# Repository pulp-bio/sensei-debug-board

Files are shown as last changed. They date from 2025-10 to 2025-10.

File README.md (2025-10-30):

# SENSEI Debug Board

This repository contains the hardware design files for the **SENSEI Debug Board**, a dedicated debugging and programming interface designed to facilitate rapid development and prototyping on the SENSEI platform.

## Overview

The **SENSEI Debug Board** simplifies the development process, facilitating flashing, debugging, and testing hardware designed around the SENSEI Base Board and its extension shields. Both the base board and any additional shield boards can be directly connected.

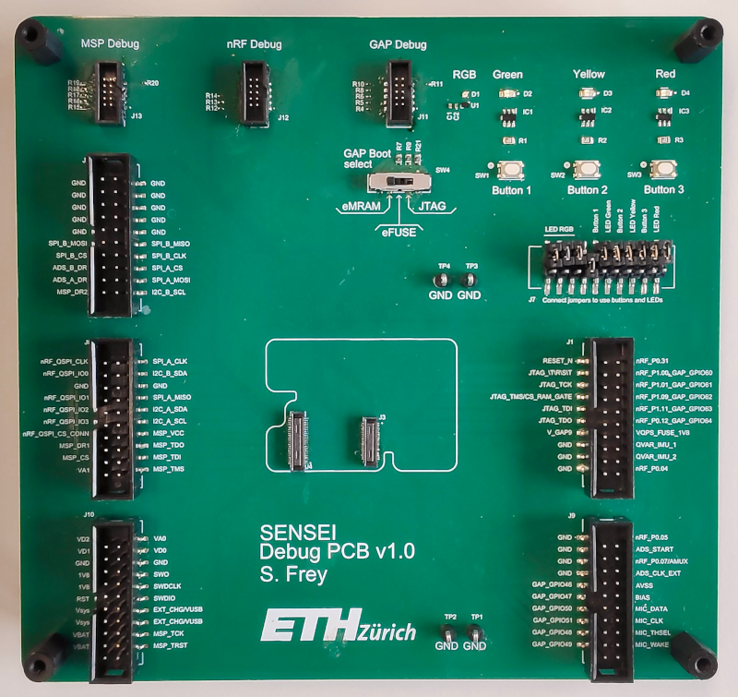
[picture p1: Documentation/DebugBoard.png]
Altium Screenshot


### Key Features
- **Integrated Debug Interfaces**
  - Dedicated debug and flash connectors for GAP9, nRF5340, and MSP SoCs.
- **Easy Signal and Power Access**
  - Pin headers provide direct access to all signals and power rails on the board-to-board connectors.
- **User-Friendly Interface**
  - Onboard LEDs and buttons for system status indication and interaction during development and debugging.

## Important Notes
- For SENSEI Base Board v1.0, ensure that the GAP9 is connected to the SPI bus (controlled by nRF) to use the JTAG programming header on the Debug Board. Alternatively, the JTAG header on the break-off part of the Base Board can be used.

## Changelog
A changelog is available in the [Changelog.md](Changelog.md) file, which tracks all major updates and revisions to the board's design and documentation.

## Contributors
- **Sebastian Frey** ([sefrey@iis.ee.ethz.ch](mailto:sefrey@iis.ee.ethz.ch))
- **Philip Wiese** ([wiesep@iis.ee.ethz.ch](mailto:wiesep@iis.ee.ethz.ch))

## License
This repository makes use of the following licenses:
- for all *hardware*: Solderpad Hardware License Version 0.51
- for all *images*: Creative Commons Attribution 4.0 International
License][cc-by]

For further information have a look at the license files: `LICENSE.hw`, `LICENSE.images`

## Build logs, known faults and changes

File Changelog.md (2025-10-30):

# Changelog

## Version 1.1 (unreleased)
- Added reset buttons
- Changed header for jumpers
- Added note about SENSEI Base Board v1.0 to enable programming

## Version 1.0 (03.07.2025)
- Inital version

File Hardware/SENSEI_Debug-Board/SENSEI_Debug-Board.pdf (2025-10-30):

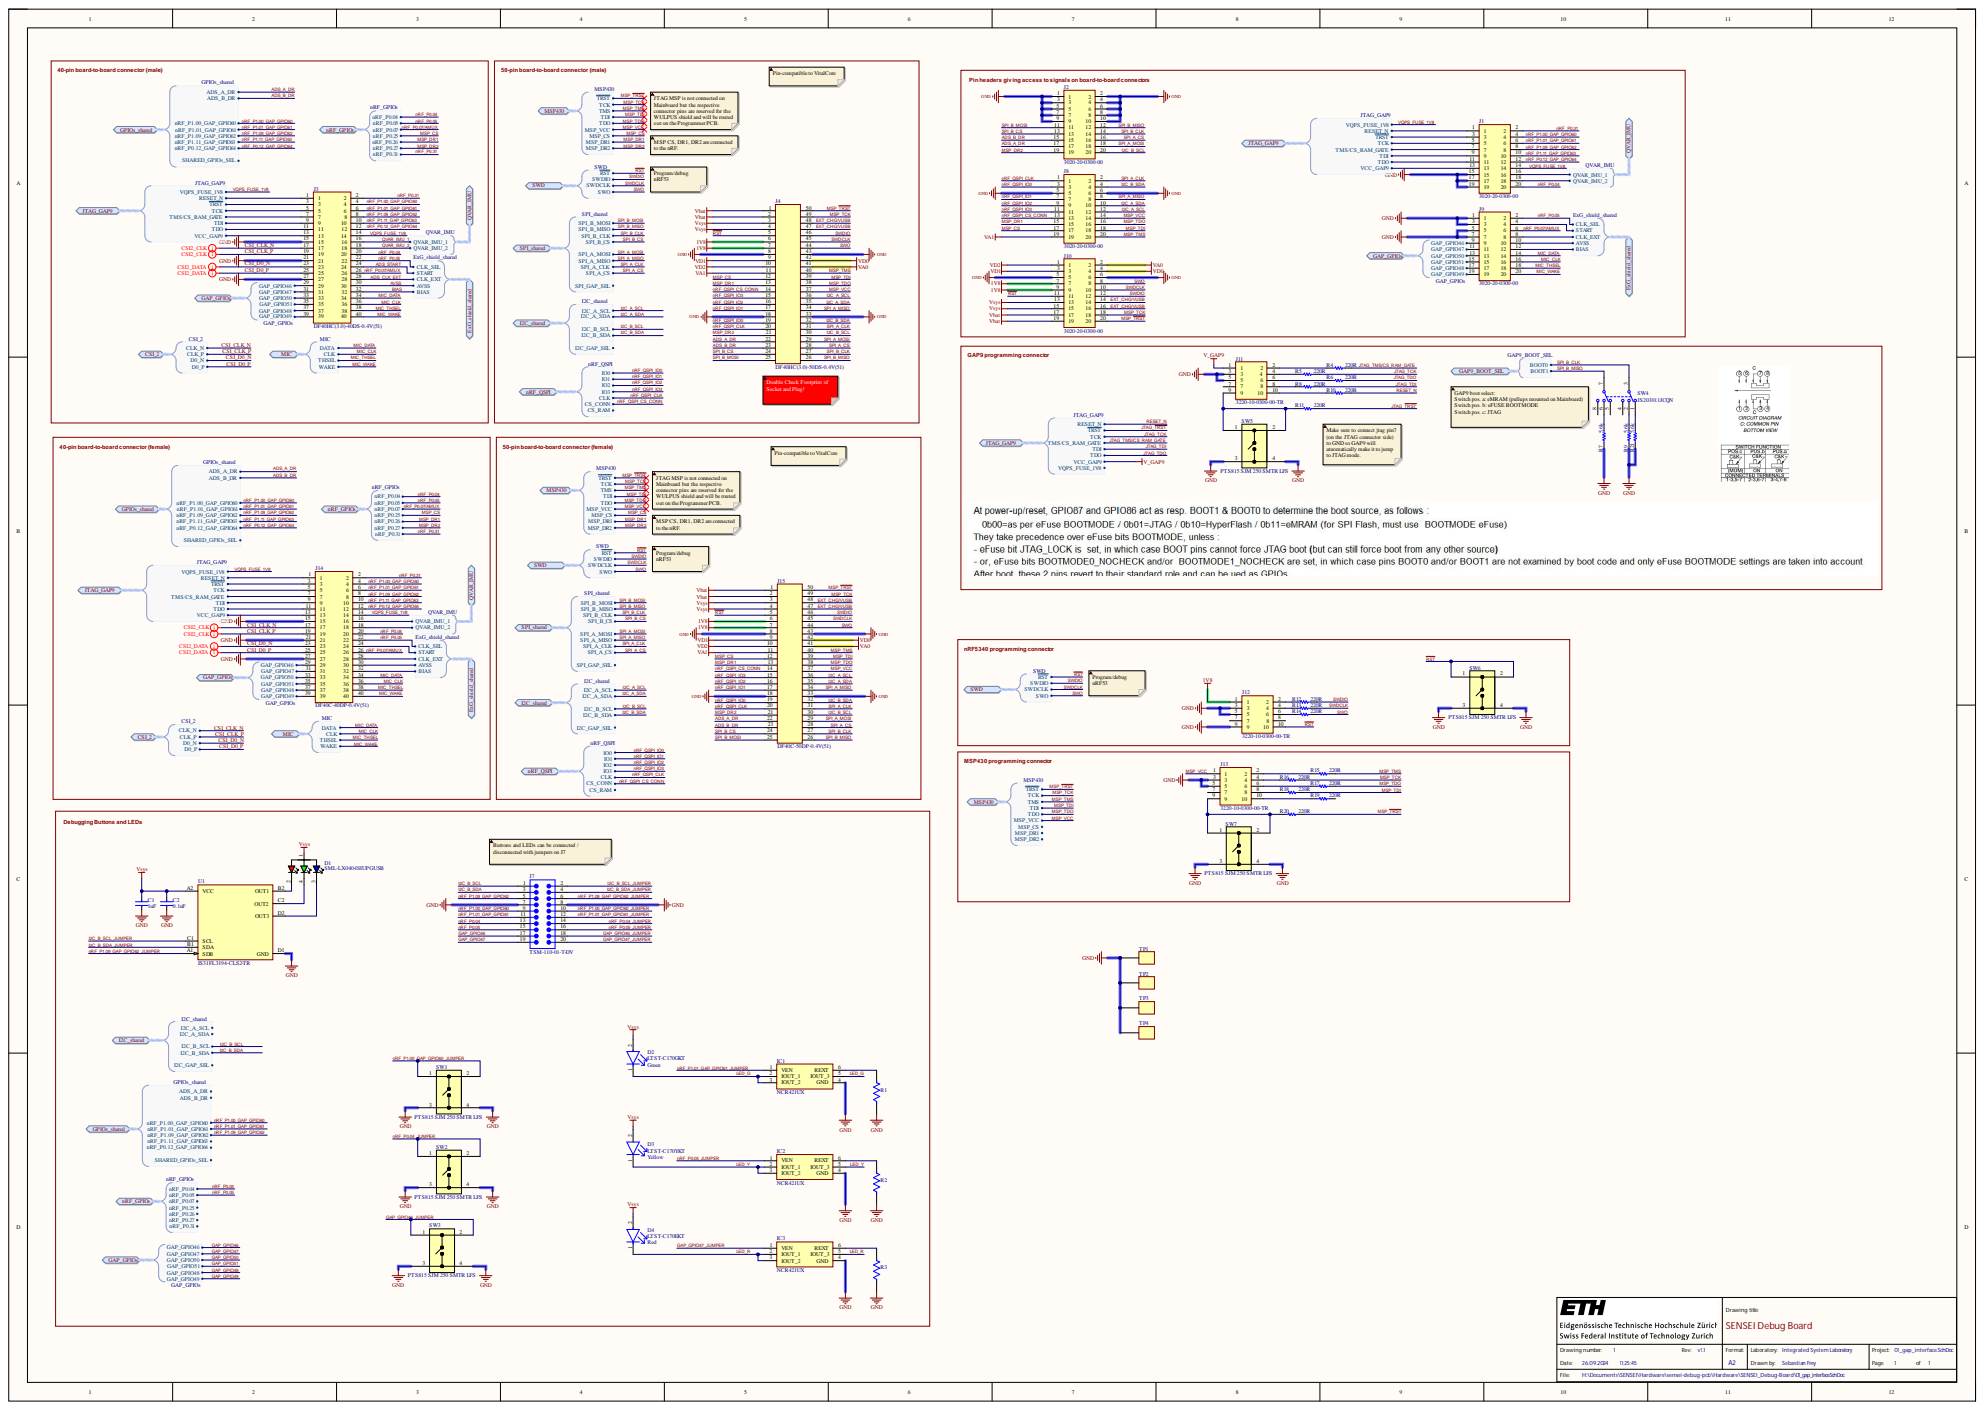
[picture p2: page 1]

40-pin board-to-board connector (male)

50-pin board-to-board connector (male)

Pin-compatible to VitalCore

Pin headers giv ing access to signals on board-to-board connectors

JTAG MSP is not connected on
Mainboard but the respective
connector pins are reserved for the
WULPUS shield and will be routed
out on the Programmer PCB.

MSP CS, DR1, DR2 are connected
to the nRF.

Double Check Footprint of
Socket and Plug!

GAP9 boot select:
Switch pos. a: eMRAM (pullups mounted on Mainboard)
Switch pos. b: eFUSE BOOTMODE
Switch pos. c: JTAG

Make sure to connect jtag pin7
(on the JTAG connector side)
to GND so GAP9 will
atuomatically make it to jump
to JTAG mode.

Debugging Buttons and LEDs

Buttons and LEDs can be connected /
disconnected with jumpers on J7

Laboratory: Integrated System Laboratory

H:\Documents\SENSEI\Hardware\sensei-debug-pcb\Hardware\SENSEI_Debug-Board\01_gap_interface.SchDoc

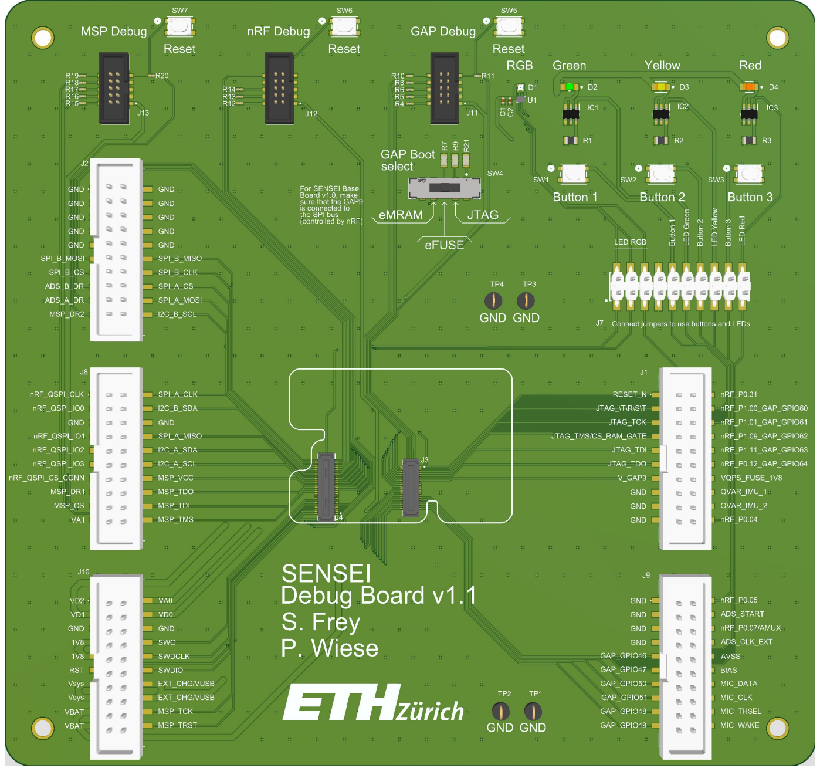
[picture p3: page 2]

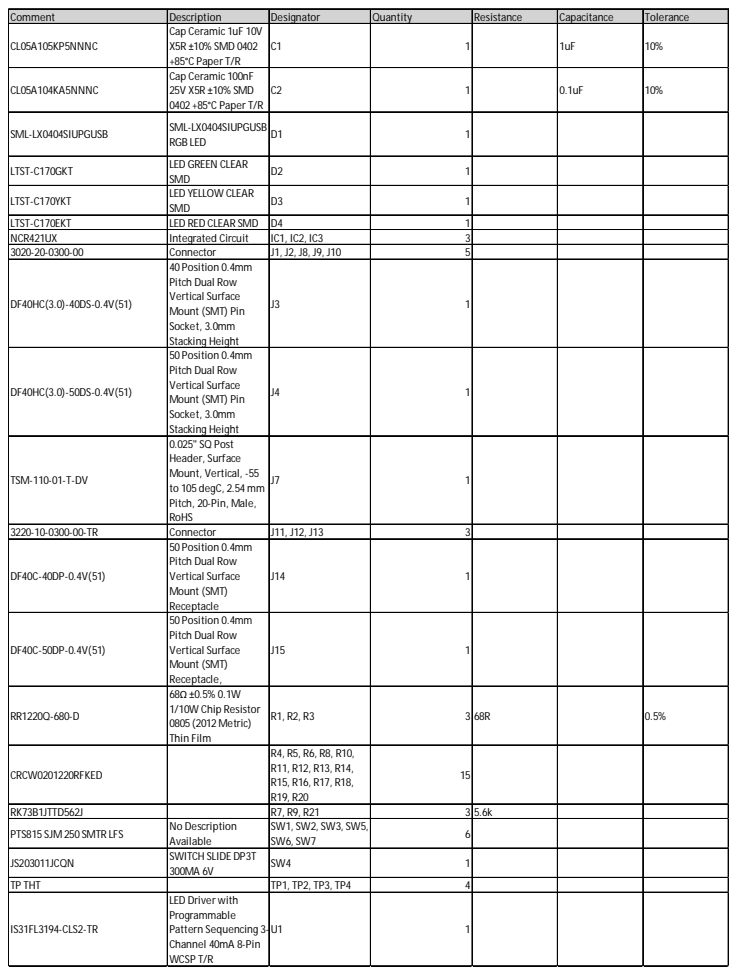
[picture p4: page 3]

Comment | Description | Designator | Quantity | Resistance | Capacitance | Tolerance
CL05A105KP5NNNC | Cap Ceramic 1uF 10V X5R ±10% SMD 0402 +85°C Paper T/R | C1 | 1 | | 1uF | 10%

CL05A104KA5NNNC | Cap Ceramic 100nF 25V X5R ±10% SMD 0402 +85°C Paper T/R | C2 | 1 | | 0.1uF | 10%

SML-LX0404SIUPGUSB | SML-LX0404SIUPGUSB RGB LED | D1 | 1

LTST-C170GKT | LED GREEN CLEAR SMD | D2 | 1

LTST-C170YKT | LED YELLOW CLEAR SMD | D3 | 1

LTST-C170EKT | LED RED CLEAR SMD | D4 | 1
NCR421UX | Integrated Circuit | IC1, IC2, IC3 | 3
3020-20-0300-00 | Connector | J1, J2, J8, J9, J10 | 5
DF40HC(3.0)-40DS-0.4V(51) | 40 Position 0.4mm Pitch Dual Row Vertical Surface Mount (SMT) Pin Socket, 3.0mm Stacking Height | J3 | 1

DF40HC(3.0)-50DS-0.4V(51) | 50 Position 0.4mm Pitch Dual Row Vertical Surface Mount (SMT) Pin Socket, 3.0mm Stacking Height | J4 | 1

TSM-110-01-T-DV | 0.025" SQ Post Header, Surface Mount, Vertical, -55 to 105 degC, 2.54mm Pitch, 20-Pin, Male, RoHS | J7 | 1

3220-10-0300-00-TR | Connector | J11, J12, J13 | 3
DF40C-40DP-0.4V(51) | 50 Position 0.4mm Pitch Dual Row Vertical Surface Mount (SMT) Receptacle | J14 | 1

DF40C-50DP-0.4V(51) | 50 Position 0.4mm Pitch Dual Row Vertical Surface Mount (SMT) Receptacle, | J15 | 1

RR1220Q-680-D | 68Ω ±0.5% 0.1W 1/10W Chip Resistor 0805 (2012 Metric) Thin Film | R1, R2, R3 | 3 68R | | | 0.5%

CRCW0201220RFKED | | R4, R5, R6, R8, R10, R11, R12, R13, R14, R15, R16, R17, R18, R19, R20 | 15

RK73B1JTTD562J | | R7, R9, R21 | 3 5.6k
PTS815 SJM 250 SMTR LFS | No Description Available | SW1, SW2, SW3, SW5, SW6, SW7 | 6

JS203011JCQN | SWITCH SLIDE DP3T 300MA 6V | SW4 | 1

TP THT | | TP1, TP2, TP3, TP4 | 4
IS31FL3194-CLS2-TR | LED Driver with Programmable Pattern Sequencing 3-Channel 40mA 8-Pin WCSP T/R | U1 | 1
